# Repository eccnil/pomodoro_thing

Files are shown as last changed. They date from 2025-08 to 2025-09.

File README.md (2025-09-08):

# Contador

Este proyecto permite fabricar un dispositivo creando una placa pcb, su circuito y su caja

render

El resultado es un aparato que puede servir como contador, como reloj de cocina o como metrónomo.
Aunque su funcionalidad no es su proprosito, se han añadido estas para dar vistosidad.

Conultese el [manual de operación](ManualUsuario.md) para saber como
operar el producto final

## Organización

Existen 3 carpetas, que recogen las principales partes de este proyecto:

| Carpeta | Descripción | Uso |
| --- | --- | --- |
| [shema](shema) | Creación de la placa | KiCad 9 |
| [case](case) | Carcasa exterior | Freecad 1  |
| [codigo](codigo) | Software (c++ / Arduino) | PlatformIO |

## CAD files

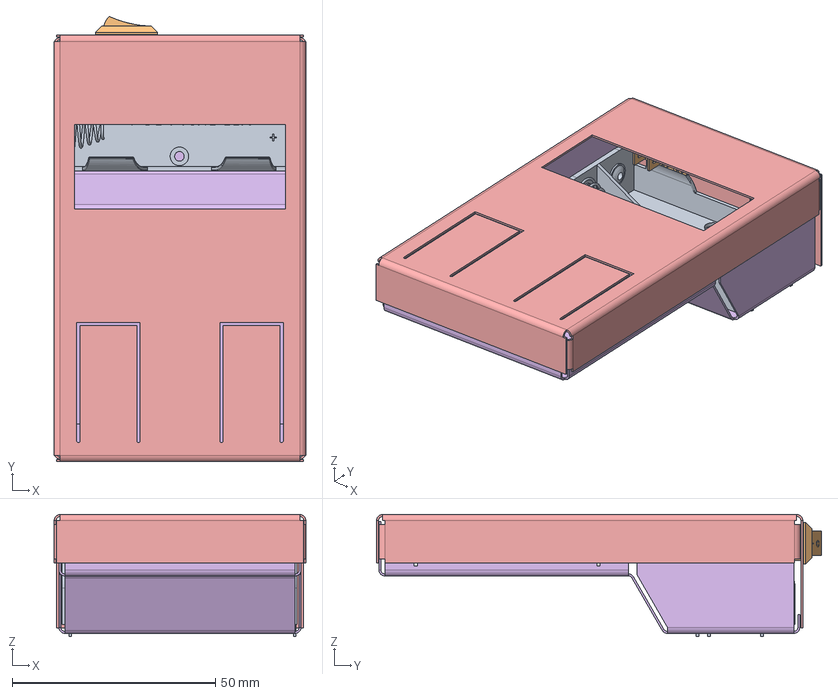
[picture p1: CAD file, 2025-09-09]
case/counter_case_blended.FCStd
62.0 x 109.6 x 30.1 mm
AABattery Holder
interruptor KS 10x15
M3x5-Screw
M3x5-Screw001
Cover
Back

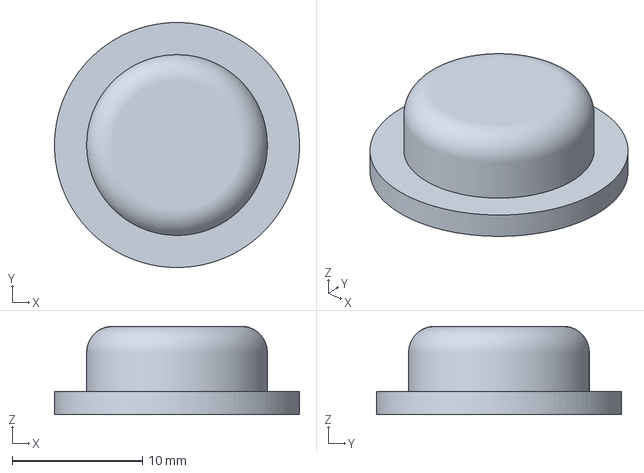
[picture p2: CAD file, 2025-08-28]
case/counter_case-caseRigthButton.3mf
18.8 x 18.8 x 6.80 mm

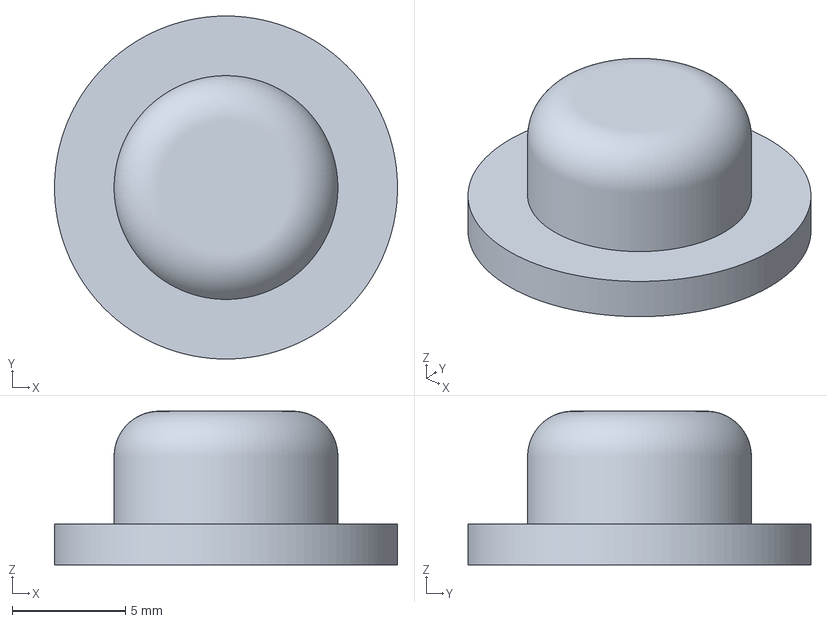
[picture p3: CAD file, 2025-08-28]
case/counter_case-caseLeftButton.3mf
15.2 x 15.2 x 6.80 mm

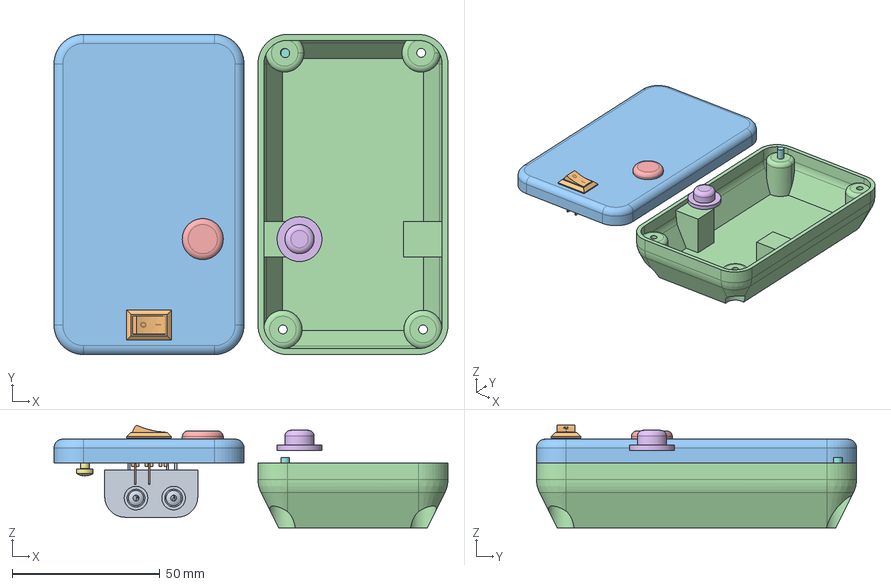
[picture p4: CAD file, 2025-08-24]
case/counter_case.FCStd
133.3 x 108.3 x 34.7 mm
AABattery Holder
interruptor KS 10x15
up case
bottom case
RigthButton
LeftButton
M3x5-Screw
M3x5-Screw001

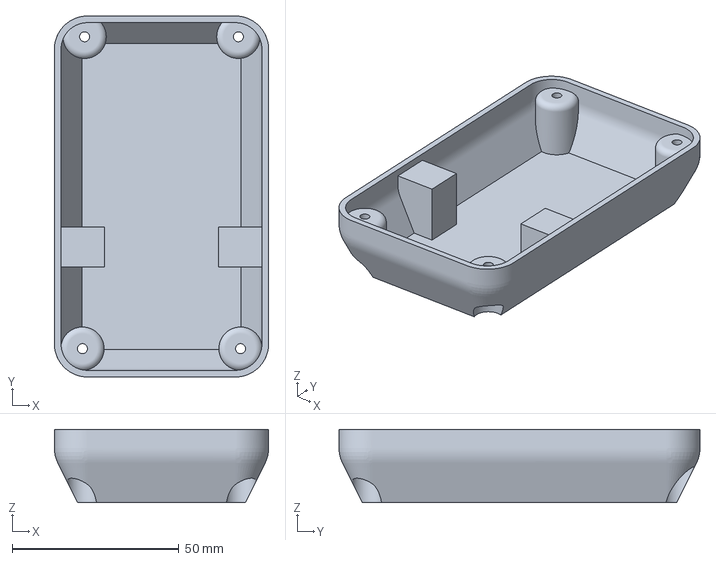
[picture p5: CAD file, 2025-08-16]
case/counter_case-casebottom case.3mf
64.3 x 108.3 x 22.0 mm

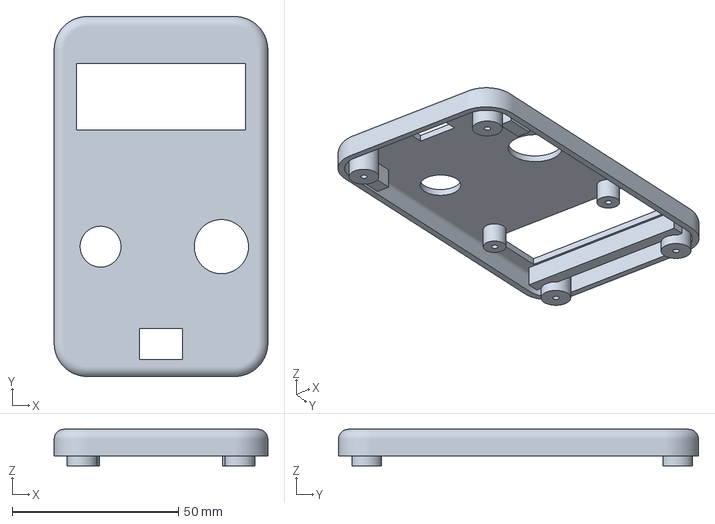
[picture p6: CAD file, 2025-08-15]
case/counter_case-casePad002.3mf
64.3 x 108.3 x 11.0 mm

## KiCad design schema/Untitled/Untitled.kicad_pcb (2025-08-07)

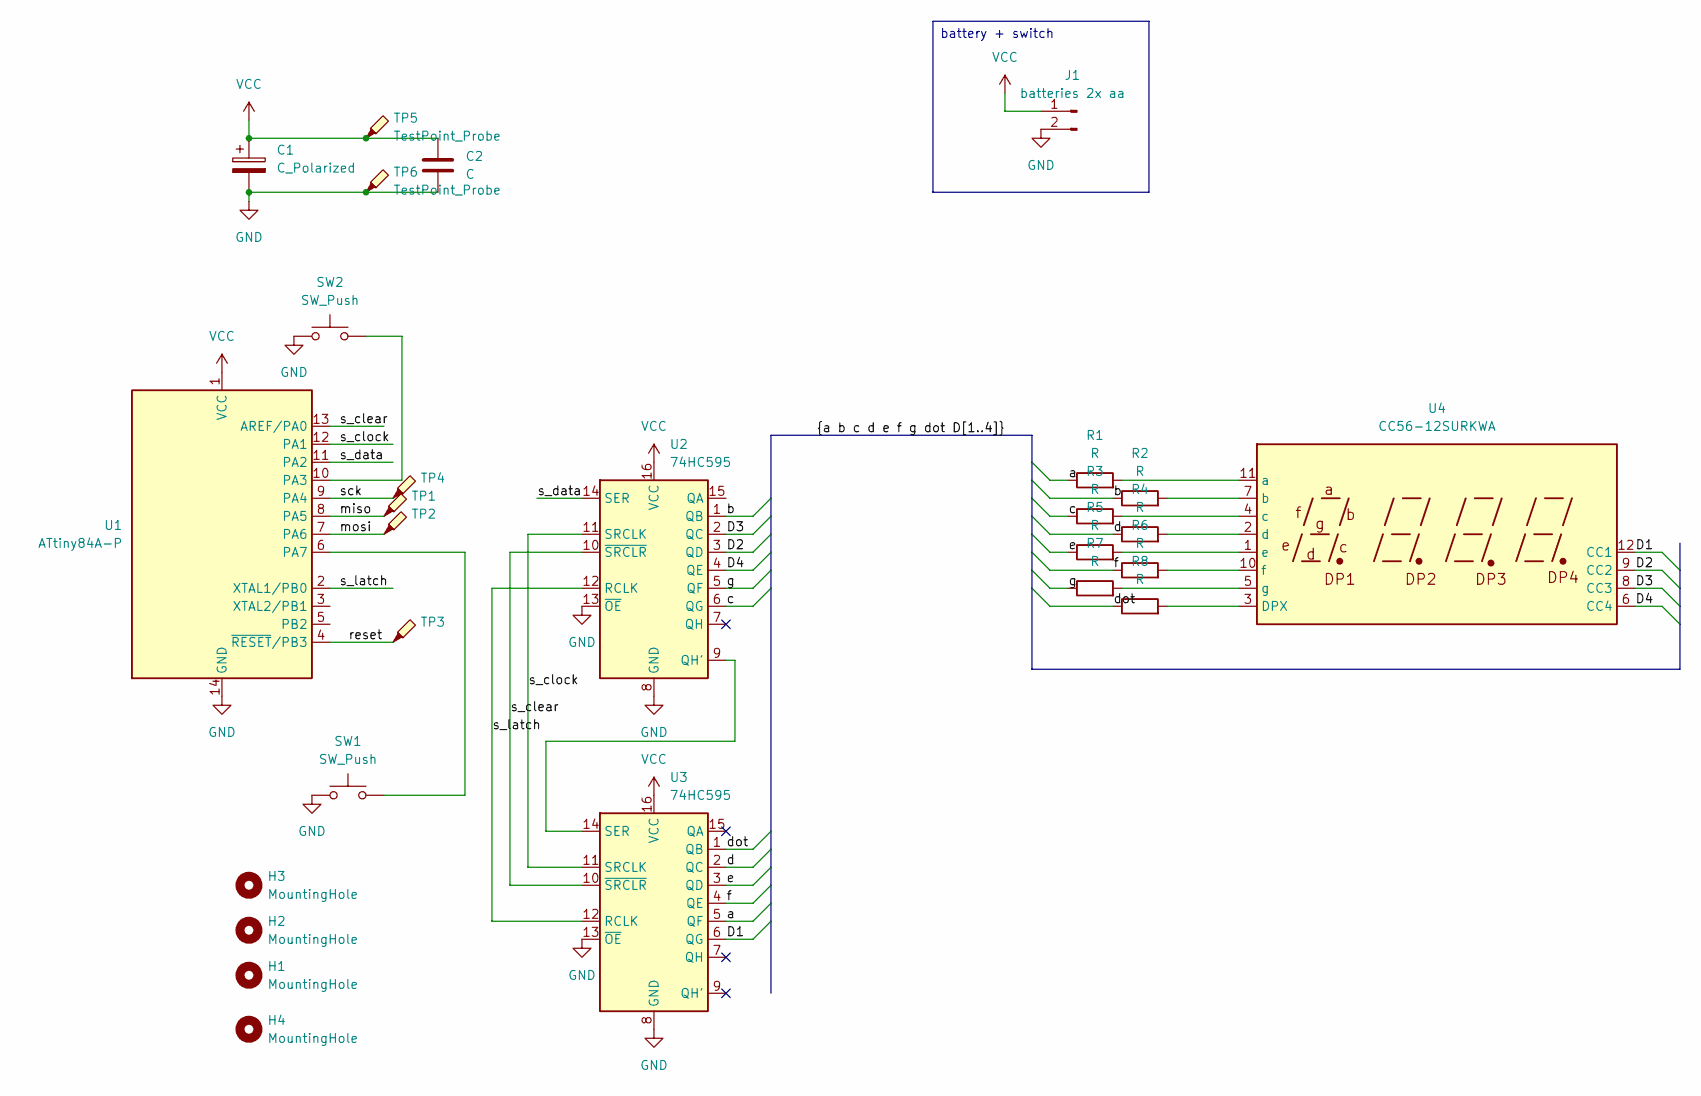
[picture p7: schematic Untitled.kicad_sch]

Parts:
C1: C_Polarized; CP_Radial_D5.0mm_P2.50mm
C2: C; C_Disc_D5.0mm_W2.5mm_P5.00mm
H1, H2, H3, H4: MountingHole; MountingHole_3.2mm_M3
J1: batteries 2x aa; SolderWire-0.1sqmm_1x02_P3.6mm_D0.4mm_OD1mm_Relief
R1, R2, R3, R4, R5, R6, R7, R8: R; R_1206_3216Metric_Pad1.30x1.75mm_HandSolder
SW1, SW2: SW_Push; SW_SPST_Omron_B3FS-101xP
TP1, TP2, TP3, TP4, TP5, TP6: TestPoint_Probe; Pin_D1.0mm_L10.0mm
U1: ATtiny84A-P; DIP-14_W7.62mm_SMDSocket_SmallPads
U2, U3: 74HC595; DIP-16_W7.62mm_SMDSocket_SmallPads
U4: CC56-12SURKWA; CA56-12SURKWA

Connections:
/D1: U3.6 (QG), U4.12 (CC1)
/D2: U2.3 (QD), U4.9 (CC2)
/D3: U2.2 (QC), U4.8 (CC3)
/D4: U2.4 (QE), U4.6 (CC4)
/a: R1.1, U3.5 (QF)
/b: R2.1, U2.1 (QB)
/c: R3.1, U2.6 (QG)
/d: R4.1, U3.2 (QC)
/dot: R8.1, U3.1 (QB)
/e: R5.1, U3.3 (QD)
/f: R6.1, U3.4 (QE)
/g: R7.1, U2.5 (QF)
/miso: TP1.1, U1.8 (PA5)
/mosi: TP2.1, U1.7 (PA6)
/reset: TP3.1, U1.4 (~RESET/PB3)
/s_clear: U1.13 (AREF/PA0), U2.10 (~SRCLR), U3.10 (~SRCLR)
/s_clock: U1.12 (PA1), U2.11 (SRCLK), U3.11 (SRCLK)
/s_data: U1.11 (PA2), U2.14 (SER)
/s_latch: U1.2 (XTAL1/PB0), U2.12 (RCLK), U3.12 (RCLK)
/sck: TP4.1, U1.9 (PA4)
GND: C1.2, C2.2, J1.2, SW1.1, SW2.1, TP6.1, U1.14 (GND), U2.8 (GND), U2.13 (~OE), U3.8 (GND), U3.13 (~OE)
unnamed: SW2.2, U1.10 (PA3)
unnamed: SW1.2, U1.6 (PA7)
unnamed: U2.9 (QH'), U3.14 (SER)
unnamed: R8.2, U4.3 (DPX)
unnamed: R1.2, U4.11 (a)
unnamed: R2.2, U4.7 (b)
unnamed: R3.2, U4.4 (c)
unnamed: R4.2, U4.2 (d)
unnamed: R5.2, U4.1 (e)
unnamed: R6.2, U4.10 (f)
unnamed: R7.2, U4.5 (g)
VCC: C1.1, C2.1, J1.1, TP5.1, U1.1 (VCC), U2.16 (VCC), U3.16 (VCC)

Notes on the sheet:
battery + switch

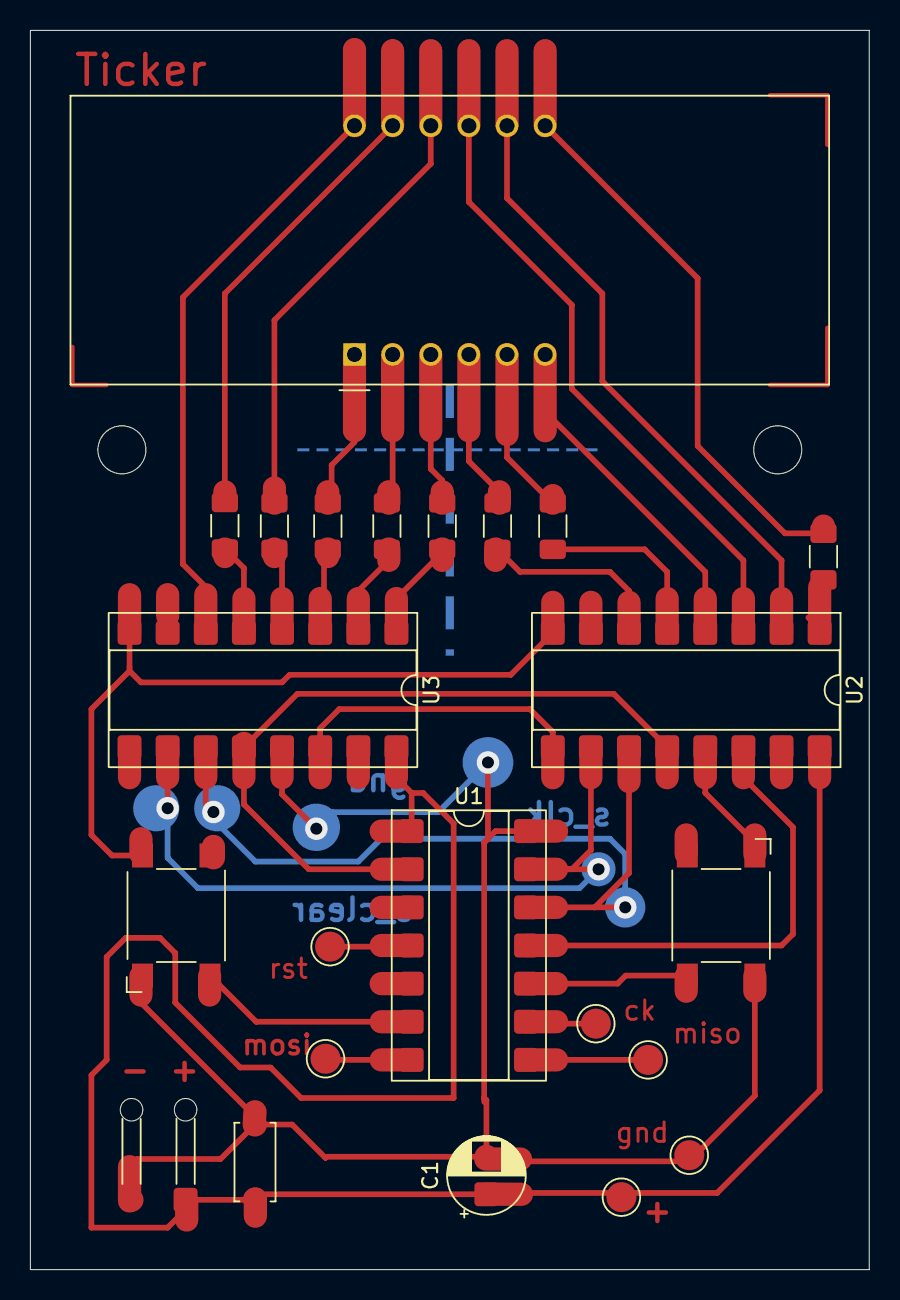
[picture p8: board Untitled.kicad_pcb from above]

Board: 2 copper layers, 55.9 x 82.6 mm, 25 parts (0 on the bottom side), 33 nets.

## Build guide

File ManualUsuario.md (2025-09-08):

# Manual de uso

## Descripción

El aparato cuenta con dos botones.

- El botón A. es el más gránde y está situado a la derecha
- El botón B. es el más pequeño y está situado a la izquierda

bajo ellos está el interruptor que permite encender el aparato.

## Modos de operacion

Existen 3 modoso de opaeracion
(estrategias de operacion en el codigo fuente).

Se activan manteniendo pulsado un botón durante el arranque
(Pulsar un botón -o no- mientras se activa el interruptor).

| Modo | Botón | Descripción |
| --- | --- | --- |
| Contador | B (izquierdo) | Contaodr de pulsaciones |
| Metrónomo | A (derecho) | Marca el tempo (sin sonido) |
| Temporizador | - ninguno - | Reloj de cuenta regresiva para cocina o para [Pomodoro](https://es.wikipedia.org/wiki/Técnica_Pomodoro) |

Estos modos se describen a continuación.

## Contador

Modo original de este proyecto y que le da nombre. Permite contar cosas sin llevar la cuenta mentalmente.

Con el botón A se incrementa la cuenta, con el botón B se decrementa la cuenta.

Para resetear la cuenta simplemente reinicie el aparato con el interruptor (manteniendo el botón B apretado).

Se pueden contar cosas hasta el límite de la pantalla: 9.999 (o -999 en negativo)

## Metrónomo

Imita un [Metrónomo](https://es.wikipedia.org/wiki/Metrónomo) convencional, pero sin sonido porque
no disponemos de un buzzer.

En el centro de la pantalla se muestran los _beats_ por segundo.
Este número se puede incrementar con el botón A o decrementar con el botón B.

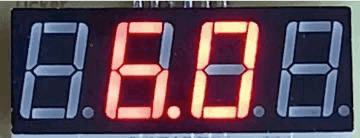
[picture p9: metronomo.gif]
display metronomo


Los puntos del display, junto con los segmentos verticales, marcan el tempo.
Cada vez que se enciende uno de los extremos es un _beat_ y marca la duración de una negra.
Los puntos marcan la duración de una semicorchea (1/4)

## Temporizador

Al encenderse el reloj marca `2 5.0 0`

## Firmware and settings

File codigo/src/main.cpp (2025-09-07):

#include <Arduino.h>
#include <avr/io.h>
#include <devices/button.hpp>
#include <devices/segments.hpp>
#include <devices/shift_register.hpp>
#include <strategies/conter_strategy.hpp>
#include <strategies/metronome.hpp>
#include <strategies/pomodoro_strategy.hpp>
#include <strategy.hpp>
#include <util/delay.h>

// gpio PINs (using alternative order)
#define SER 8   // PA2 physical 11
#define RCLK 9  // PA1 physical 12
#define MR 10   // PA0 physical 13
#define LATCH 0 // PB0 physical 2

#define BUTTON_A 7 // PA3 physical 10
#define BUTTON_B 3 // PA7 Physical 6

// global variables
Strategy *strategy;

// shiftRegiseter that drives the display inputs
shiftRegisterPins srPins = {
    .latch = LATCH, .data = SER, .clock = RCLK, .clear = MR};
ShiftRegister shift_register = ShiftRegister(srPins, BITS_TO_WRITE);

// display (4digits x 7 sgements + dot)
Segments display = Segments(shift_register);

// press button_a (right one)
Button button_a = Button(BUTTON_A);
void b_a() {
  if (strategy != NULL)
    strategy->button_a_tap();
}

// press button_a (left one)
Button button_b = Button(BUTTON_B);
void b_b() {
  if (strategy != NULL)
    strategy->button_b_tap();
}

#define DEVICE_QUANTITY 3
Device *devices[DEVICE_QUANTITY] = {&display, &button_a, &button_b};

void setup() {
  // init devices
  for (int i = 0; i < DEVICE_QUANTITY; i++) {
    devices[i]->init();
  }

  // check buttons to decide the functionality to be loaded
  button_a.poll();
  button_b.poll();
  if (button_b.is_pressed()) {
    strategy = (Strategy *)new CounterStrategy(button_a, button_b);
  } else if (button_a.is_pressed()) {
    strategy = (Strategy *)new Metronome();
  } else {
    strategy = (Strategy *)new PomodoroStrategy();
  }

  // set buttons actions to the selected functionality
  button_b.set_on_tap(b_b);
  button_a.set_on_tap(b_a);
}

void loop() {
  // update all devices
  for (int i = 0; i < DEVICE_QUANTITY; i++) {
    devices[i]->poll();
  };

  // update strategy
  strategy->display(display);
}

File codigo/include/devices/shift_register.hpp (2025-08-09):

#pragma once
#include <Arduino.h>
#include <device.h>

#define DELAY 1

struct shiftRegisterPins {
  int latch;
  int data;
  int clock;
  int clear;
};

class ShiftRegister : public Device {
  int pin_latch, pin_data, pin_clock, pin_clear, bits_to_write;
  void init_pins();
  void init_levels();
  void write_bit(bool value);
  void write_bits(int bits);
  void show();

public:
  ShiftRegister(shiftRegisterPins pins, int size_to_write);
  void init() override;
  void display_bits(int);
};

inline void ShiftRegister::init_pins() {
  pinMode(pin_data, OUTPUT);
  pinMode(pin_clock, OUTPUT);
  pinMode(pin_clear, OUTPUT);
  pinMode(pin_latch, OUTPUT);
}

inline void ShiftRegister::init_levels() {
  digitalWrite(pin_data, LOW);
  digitalWrite(pin_clock, LOW);
  digitalWrite(pin_clear, HIGH);
  digitalWrite(pin_latch, LOW);
}

inline void ShiftRegister::write_bit(bool value) {
  digitalWrite(pin_clock, LOW);
  digitalWrite(pin_data, value ? HIGH : LOW);
  digitalWrite(pin_clock, HIGH);
}

inline void ShiftRegister::write_bits(int bits) {
  for (int i = bits_to_write - 1; i >= 0; i--) {
    write_bit((bits >> i) & 1);
  }
}

inline ShiftRegister::ShiftRegister(shiftRegisterPins pins, int size_to_write) {
  pin_clear = pins.clear;
  pin_latch = pins.latch;
  pin_clock = pins.clock;
  pin_data = pins.data;
  bits_to_write = size_to_write;
}

inline void ShiftRegister::init() {
  init_pins();
  init_levels();
}

inline void ShiftRegister::show() {
  digitalWrite(pin_latch, HIGH);
  delay(DELAY);
  digitalWrite(pin_latch, LOW);
}

inline void ShiftRegister::display_bits(int bits) {
  write_bits(bits);
  show();
}

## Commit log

2025-08-05 empty schematics project
    [Untitled.kicad_pcb, Untitled.kicad_sch]
2025-08-05 configuracion para arduino as isp
2025-08-06 version funcional 1
    [Untitled.kicad_sch]
2025-08-06 button prototype
    [Untitled.kicad_sch]
2025-08-07 surrounding circuits battery, capacitors, probes, etc
    [Untitled.kicad_sch]
2025-08-07 pcb with display
    [Untitled.kicad_pcb, Untitled.kicad_sch]
2025-08-07 ultimos toques a la pcb
    [Untitled.kicad_pcb, Untitled.kicad_sch]
2025-08-07 nueva estructura de mapas de bits
2025-08-07 pcb que se realizará
    [Untitled.kicad_pcb]
2025-08-07 pines y mapas de la pcb
    el codigo hasta ahora tenia los pines y mapas de la panadera
2025-08-08 corregidos los pines para los nuevos fuses
2025-08-08 la versión 2
2025-08-11 device list usage
2025-08-11 counter case
    [counter_case.FCStd]
2025-08-11 all components to be enclosed
    [counter_case.FCStd]
2025-08-12 cambiado el interruptor
    [counter_case.FCStd]
2025-08-13 upper part of the case
    [counter_case.FCStd]
2025-08-13 upper part of the case completed
    [counter_case.FCStd]
2025-08-15 final design
    [counter_case.FCStd]
2025-08-15 construcción
    [counter_case-casePad002.3mf]
2025-08-28 button things
    [counter_case-caseLeftButton.3mf, counter_case-caseRigthButton.3mf]
2025-09-06 exhaustive switch
2025-09-07 FIXME: el metronomo va el doble de rápido
2025-09-07 assigned strategy to button A
2025-09-08 manual de usuario
2025-09-09 foldable case
    [counter_case_blended.FCStd]
2025-09-09 correcciones post-maqueta de cartulina
    [counter_case_blended.FCStd]
